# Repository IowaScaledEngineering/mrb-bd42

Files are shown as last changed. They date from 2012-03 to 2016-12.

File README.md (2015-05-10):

This is the software library, example applications, and hardware design files for the Iowa Scaled Engineering MRB-BD42 v3 4 Channel DCC block detector

The product can be found at:
http://www.iascaled.com/store/MRB-BD42

Hardware use documentation (the manual) can be found in the /doc/ directory.

Like all public Iowa Scaled Engineering designs, the MRB-BD42 is both open hardware and open source software.  Please refer to the hardware and software license files in this repository for details.

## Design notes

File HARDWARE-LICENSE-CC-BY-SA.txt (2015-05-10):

The hardware design files for the Iowa Scaled Engineering CKT-IRSENSE are
open hardware, and licensed under the Creative Commons Attribution-Share
Alike license.

A copy can be found below, or from 
  http://creativecommons.org/licenses/by-sa/4.0/legalcode
-----------------------------------------------------------------------------

Creative Commons Attribution-ShareAlike 4.0 International Public License

By exercising the Licensed Rights (defined below), You accept and agree to
be bound by the terms and conditions of this Creative Commons
Attribution-ShareAlike 4.0 International Public License ("Public License").
To the extent this Public License may be interpreted as a contract, You are
granted the Licensed Rights in consideration of Your acceptance of these
terms and conditions, and the Licensor grants You such rights in
consideration of benefits the Licensor receives from making the Licensed
Material available under these terms and conditions.

Section 1 – Definitions.

    Adapted Material means material subject to Copyright and Similar Rights
that is derived from or based upon the Licensed Material and in which the
Licensed Material is translated, altered, arranged, transformed, or
otherwise modified in a manner requiring permission under the Copyright and
Similar Rights held by the Licensor. For purposes of this Public License,
where the Licensed Material is a musical work, performance, or sound
recording, Adapted Material is always produced where the Licensed Material
is synched in timed relation with a moving image.
    Adapter's License means the license You apply to Your Copyright and
Similar Rights in Your contributions to Adapted Material in accordance with
the terms and conditions of this Public License.
    BY-SA Compatible License means a license listed at
creativecommons.org/compatiblelicenses, approved by Creative Commons as
essentially the equivalent of this Public License.
    Copyright and Similar Rights means copyright and/or similar rights
closely related to copyright including, without limitation, performance,
broadcast, sound recording, and Sui Generis Database Rights, without regard
to how the rights are labeled or categorized. For purposes of this Public
License, the rights specified in Section 2(b)(1)-(2) are not Copyright and
Similar Rights.
    Effective Technological Measures means those measures that, in the
absence of proper authority, may not be circumvented under laws fulfilling
obligations under Article 11 of the WIPO Copyright Treaty adopted on
December 20, 1996, and/or similar international agreements.
    Exceptions and Limitations means fair use, fair dealing, and/or any
other exception or limitation to Copyright and Similar Rights that applies
to Your use of the Licensed Material.
    License Elements means the license attributes listed in the name of a
Creative Commons Public License. The License Elements of this Public License
are Attribution and ShareAlike.
    Licensed Material means the artistic or literary work, database, or
other material to which the Licensor applied this Public License.
    Licensed Rights means the rights granted to You subject to the terms and
conditions of this Public License, which are limited to all Copyright and
Similar Rights that apply to Your use of the Licensed Material and that the
Licensor has authority to license.
    Licensor means the individual(s) or entity(ies) granting rights under
this Public License.
    Share means to provide material to the public by any means or process
that requires permission under the Licensed Rights, such as reproduction,
public display, public performance, distribution, dissemination,
communication, or importation, and to make material available to the public
including in ways that members of the public may access the material from a
place and at a time individually chosen by them.
    Sui Generis Database Rights means rights other than copyright resulting
from Directive 96/9/EC of the European Parliament and of the Council of 11
March 1996 on the legal protection of databases, as amended and/or
succeeded, as well as other essentially equivalent rights anywhere in the
world.
    You means the individual or entity exercising the Licensed Rights under
this Public License. Your has a corresponding meaning.

Section 2 – Scope.

    License grant.
        Subject to the terms and conditions of this Public License, the
Licensor hereby grants You a worldwide, royalty-free, non-sublicensable,
non-exclusive, irrevocable license to exercise the Licensed Rights in the
Licensed Material to:
            reproduce and Share the Licensed Material, in whole or in part;
and
            produce, reproduce, and Share Adapted Material.
        Exceptions and Limitations. For the avoidance of doubt, where
Exceptions and Limitations apply to Your use, this Public License does not
apply, and You do not need to comply with its terms and conditions.
        Term. The term of this Public License is specified in Section 6(a).
        Media and formats; technical modifications allowed. The Licensor
authorizes You to exercise the Licensed Rights in all media and formats
whether now known or hereafter created, and to make technical modifications
necessary to do so. The Licensor waives and/or agrees not to assert any
right or authority to forbid You from making technical modifications
necessary to exercise the Licensed Rights, including technical modifications
necessary to circumvent Effective Technological Measures. For purposes of
this Public License, simply making modifications authorized by this Section
2(a)(4) never produces Adapted Material.
        Downstream recipients.
            Offer from the Licensor – Licensed Material. Every recipient of
the Licensed Material automatically receives an offer from the Licensor to
exercise the Licensed Rights under the terms and conditions of this Public
License.
            Additional offer from the Licensor – Adapted Material. Every
recipient of Adapted Material from You automatically receives an offer from
the Licensor to exercise the Licensed Rights in the Adapted Material under
the conditions of the Adapter’s License You apply.
            No downstream restrictions. You may not offer or impose any
additional or different terms or conditions on, or apply any Effective
Technological Measures to, the Licensed Material if doing so restricts
exercise of the Licensed Rights by any recipient of the Licensed Material.
        No endorsement. Nothing in this Public License constitutes or may be
construed as permission to assert or imply that You are, or that Your use of
the Licensed Material is, connected with, or sponsored, endorsed, or granted
official status by, the Licensor or others designated to receive attribution
as provided in Section 3(a)(1)(A)(i).

    Other rights.
        Moral rights, such as the right of integrity, are not licensed under
this Public License, nor are publicity, privacy, and/or other similar
personality rights; however, to the extent possible, the Licensor waives
and/or agrees not to assert any such rights held by the Licensor to the
limited extent necessary to allow You to exercise the Licensed Rights, but
not otherwise.
        Patent and trademark rights are not licensed under this Public
License.
        To the extent possible, the Licensor waives any right to collect
royalties from You for the exercise of the Licensed Rights, whether directly
or through a collecting society under any voluntary or waivable statutory or
compulsory licensing scheme. In all other cases the Licensor expressly
reserves any right to collect such royalties.

Section 3 – License Conditions.

Your exercise of the Licensed Rights is expressly made subject to the
following conditions.

    Attribution.

        If You Share the Licensed Material (including in modified form), You
must:
            retain the following if it is supplied by the Licensor with the
Licensed Material:
                identification of the creator(s) of the Licensed Material
and any others designated to receive attribution, in any reasonable manner
requested by the Licensor (including by pseudonym if designated);
                a copyright notice;
                a notice that refers to this Public License;
                a notice that refers to the disclaimer of warranties;
                a URI or hyperlink to the Licensed Material to the extent
                reasonably practicable;
            indicate if You modified the Licensed Material and retain an
indication of any previous modifications; and
            indicate the Licensed Material is licensed under this Public
License, and include the text of, or the URI or hyperlink to, this Public
License.
        You may satisfy the conditions in Section 3(a)(1) in any reasonable
manner based on the medium, means, and context in which You Share the
Licensed Material. For example, it may be reasonable to satisfy the
conditions by providing a URI or hyperlink to a resource that includes the
required information.
        If requested by the Licensor, You must remove any of the information
required by Section 3(a)(1)(A) to the extent reasonably practicable.
    ShareAlike.

    In addition to the conditions in Section 3(a), if You Share Adapted
Material You produce, the following conditions also apply.
        The Adapter’s License You apply must be a Creative Commons license
with the same License Elements, this version or later, or a BY-SA Compatible
License.
        You must include the text of, or the URI or hyperlink to, the
Adapter's License You apply. You may satisfy this condition in any
reasonable manner based on the medium, means, and context in which You Share
Adapted Material.
        You may not offer or impose any additional or different terms or
conditions on, or apply any Effective Technological Measures to, Adapted
Material that restrict exercise of the rights granted under the Adapter's
License You apply.

Section 4 – Sui Generis Database Rights.

Where the Licensed Rights include Sui Generis Database Rights that apply to
Your use of the Licensed Material:

    for the avoidance of doubt, Section 2(a)(1) grants You the right to
extract, reuse, reproduce, and Share all or a substantial portion of the
contents of the database;
    if You include all or a substantial portion of the database contents in
a database in which You have Sui Generis Database Rights, then the database
in which You have Sui Generis Database Rights (but not its individual
contents) is Adapted Material, including for purposes of Section 3(b); and
    You must comply with the conditions in Section 3(a) if You Share all or
a substantial portion of the contents of the database.

For the avoidance of doubt, this Section 4 supplements and does not replace
Your obligations under this Public License where the Licensed Rights include
other Copyright and Similar Rights.

Section 5 – Disclaimer of Warranties and Limitation of Liability.

    Unless otherwise separately undertaken by the Licensor, to the extent
possible, the Licensor offers the Licensed Material as-is and as-available,
and makes no representations or warranties of any kind concerning the
Licensed Material, whether express, implied, statutory, or other. This
includes, without limitation, warranties of title, merchantability, fitness
for a particular purpose, non-infringement, absence of latent or other
defects, accuracy, or the presence or absence of errors, whether or not
known or discoverable. Where disclaimers of warranties are not allowed in
full or in part, this disclaimer may not apply to You.
    To the extent possible, in no event will the Licensor be liable to You
on any legal theory (including, without limitation, negligence) or otherwise
for any direct, special, indirect, incidental, consequential, punitive,
exemplary, or other losses, costs, expenses, or damages arising out of this
Public License or use of the Licensed Material, even if the Licensor has
been advised of the possibility of such losses, costs, expenses, or damages.
Where a limitation of liability is not allowed in full or in part, this
limitation may not apply to You.

    The disclaimer of warranties and limitation of liability provided above
shall be interpreted in a manner that, to the extent possible, most closely
approximates an absolute disclaimer and waiver of all liability.

Section 6 – Term and Termination.

    This Public License applies for the term of the Copyright and Similar
Rights licensed here. However, if You fail to comply with this Public
License, then Your rights under this Public License terminate automatically.

    Where Your right to use the Licensed Material has terminated under
Section 6(a), it reinstates:
        automatically as of the date the violation is cured, provided it is
cured within 30 days of Your discovery of the violation; or
        upon express reinstatement by the Licensor.
    For the avoidance of doubt, this Section 6(b) does not affect any right
the Licensor may have to seek remedies for Your violations of this Public
License.
    For the avoidance of doubt, the Licensor may also offer the Licensed
Material under separate terms or conditions or stop distributing the
Licensed Material at any time; however, doing so will not terminate this
Public License.
    Sections 1, 5, 6, 7, and 8 survive termination of this Public License.

Section 7 – Other Terms and Conditions.

    The Licensor shall not be bound by any additional or different terms or
conditions communicated by You unless expressly agreed.
    Any arrangements, understandings, or agreements regarding the Licensed
Material not stated herein are separate from and independent of the terms
and conditions of this Public License.

Section 8 – Interpretation.

    For the avoidance of doubt, this Public License does not, and shall not
be interpreted to, reduce, limit, restrict, or impose conditions on any use
of the Licensed Material that could lawfully be made without permission
under this Public License.
    To the extent possible, if any provision of this Public License is
deemed unenforceable, it shall be automatically reformed to the minimum
extent necessary to make it enforceable. If the provision cannot be
reformed, it shall be severed from this Public License without affecting the
enforceability of the remaining terms and conditions.
    No term or condition of this Public License will be waived and no
failure to comply consented to unless expressly agreed to by the Licensor.
    Nothing in this Public License constitutes or may be interpreted as a
limitation upon, or waiver of, any privileges and immunities that apply to
the Licensor or You, including from the legal processes of any jurisdiction
or authority.

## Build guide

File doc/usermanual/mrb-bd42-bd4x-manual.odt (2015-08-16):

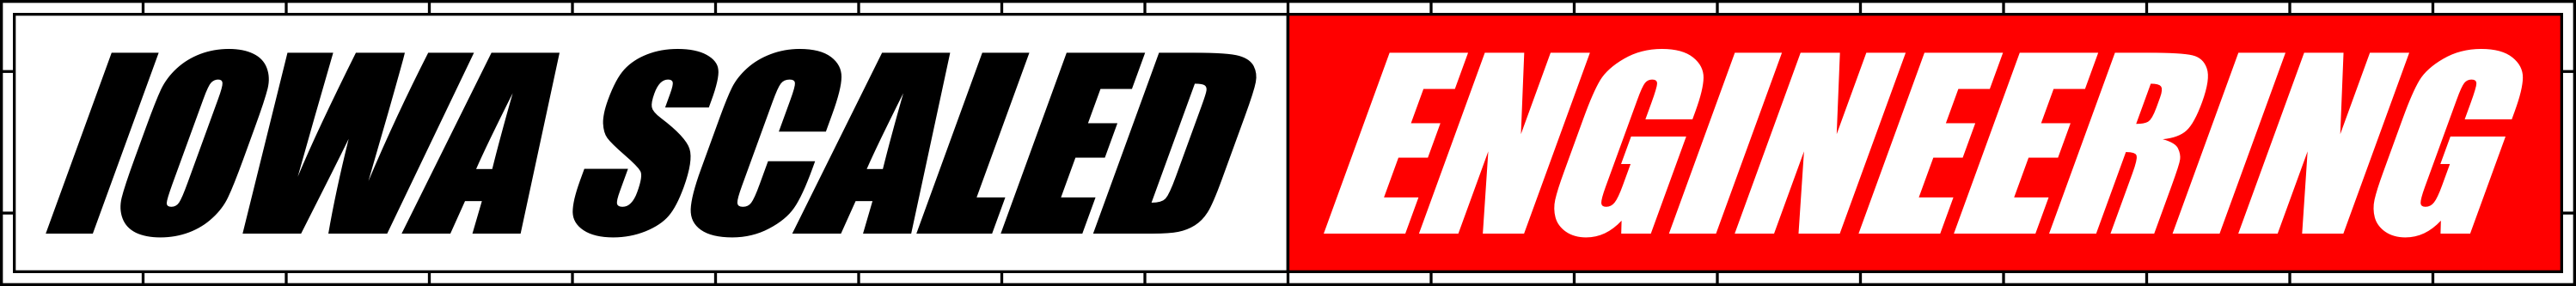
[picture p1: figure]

MRB-BD42 / MRB-BD4X v3 User Manual

# Features

- Four extremely sensitive (12-15k ohms) independent channels
- Easy per-channel sensitivity adjustment
- Isolated detection to prevent coupling track power and signal systems
- Simple installation doesn't require cutting track power wires
- Open source MRBus interface (MRB-BD42 version only)
- Expansion ports for up to two extra MRB-BD4X on every MRB-BD42 for up to 8 extra channels
- Four easy-to-use logic level outputs (5V @ 15mA maximum, MRB-BD4X version only)

# Applications

- Block detection for signaling systems
- Activate grade crossing signals
- Monitor train progress in hidden areas
- Simulating a spring switch using an MRServo switch machine

# Differences between MRB-BD42 vs MRB-BD4X

MRB-BD42 detectors are designed to integrate with MRBus, an open source model railroad control bus based on RS-485 and promoted by Iowa Scaled Engineering. For more information, see http://www.mrbus.org

MRB-BD4X detectors are designed to provide four 5V logic level outputs, each corresponding to one channel of the detector. These can be used independently, connected to your own signal logic, or as expansion modules for a MRB-BD42.

# Operation

The MRB-BD42/BD4X are four-channel current-based model railroad block occupancy detectors for DCC layouts. They require the alternating DCC signal to operate reliably, and will either not work or work erratically with most DC layouts.

The BD42/BD4X use current transformers – the large black tombstone-shaped items on the board – to sense small amounts of current used by DCC decoders and cars with resistor-equipped wheelsets. As such, they are electrically isolated from track power, preventing damaging currents from find stray paths between your boosters and your expensive signal gear.

# Using the MRB-BD4X Outputs

The MRB-BD4X has four logic-level outputs. Outputs will be high (5V) upon detection and low (0V) when not detecting. Never expose these outputs to a voltage outside that range, or draw more than 20 milliamps from them. To switch higher currents or voltages, please use something like our ACC-RELAY1 module.

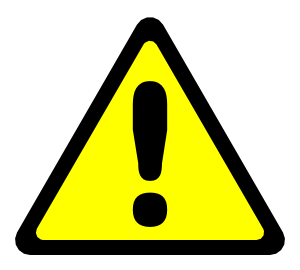
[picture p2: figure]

Do not exceed 20mA on any output, or short any output pin to 5V, GND, or any other voltage. Damage to the block detector will likely result.

# Using the MRB-BD42 Auxilliary Inputs

The MRB-BD42 comes with two 6p6c connectors that provide regulated +5VDC, GND, and four 5V logic level inputs. These can be used to connect additional MRB-BD4X expanders to have up to 12 block detection channels, or can be used for auxiliary digital inputs. Never exceed 5VDC on any of the input pins and do not draw more than 150mA from the 5V line if using them as auxiliary digital inputs from your own modules.

# Installation

Securely mount the MRB-BD42/BD4X to the model railroad benchwork using the four mounting holes provided. When choosing a mounting location, make sure nothing conductive will contact the back of the circuit board, as this may cause short circuits, malfunctions, and permanent damage.

### Powering the Detector

Both versions of the detector need a power supply to operate.

The MRB-BD42 requires 8-16VDC applied to the VIN and GND terminals. Typically this will be the MRBus power pair. The MRBus data pair should be connected to the A/B terminals, same as any MRBus node.

The MRB-BD4X can be fed from either 8-16VDC applied to the VIN and GND terminals, same as the BD42, or can be fed clean, regulated 5VDC through the 5V/GND terminals near the logic level ouputs.

Do not exceed 5V if feeding power through the 5V power supply input terminal. Power fed in through this terminal is neither regulated nor filtered, and exceeding 5V will cause the immediate destruction of the module.

### Wiring Blocks For Detection

For each block to be detected, gap at least one rail at each end of the block. Connect all the feeder wires for the gapped rail to a common bus wire, and run that wire through the center of the current transformer on the BD42/BD4X.

Only a single pass through the transformer is recommended, but for sensing very small currents, the wire can be looped through twice.

Note 1: DCC circuit breakers and auto-reversers draw a minute (but variable) amount of current, and will trigger the block detectors. Any breakers or reversing modules should be installed between the DCC booster and the BD42/BD4X, not between the detector and the track.

Note 2: For neatness and to minimize cross-talk between blocks, it's recommended to zip tie the two halves of the wire above the current transformer.

### Setting the Sensitivity

Contrary to popular belief, an empty track block does not always draw zero current. Because of resistive leakage through scenery (including wooden ties in varying humidity) and capacitive effects between the rails and feeder wires, there's often a very small leakage current.

The MRB-BD42/BD4X has an adjustment potentiometer (pot) on each channel to allow you to tune out this leakage current. Rotating the potentiometer clockwise will increase the sensitivity (detects occupancy at lower currents) and counter-clockwise will decrease sensitivity.

To tune each channel:

1) Turn on your DCC system and make sure no equipment is in the block.

2) If the red “detect” LED is on for the channel you're working on, you can skip this step. Otherwise, use a small flathead screwdriver to slowly turn the potentiometer clockwise until the red light just comes on.

3) Now turn the pot counter-clockwise slowly until the LED turns off. At this point, your channel is calibrated.

4) While not typical, it is possible that changes to the layout – humidity, temperature, ballasting the track, etc. - can change the leakage current. You may need to repeat the procedure if you get false occupancy in the future.

# Configuration Values

As a MRBus-based device, the MRB-BD42 has a number of configuration registers that can be used to change how the device operates.

The MRB-BD4X also uses many of these registers, but has no network through which to update them conveniently. For most applications, the default values will work without any issues. However, for more specialized applications, they can be changed from their default value using an AVR programmer.

CV | Purpose | Default | Possible Values | Description
0x00 | Node Address | 3 | 1-254 | The node address for this MRB-BD42
0x02 0x03 | Update Time H Update Time L | 20 | 1-65535 | Interval, in 1/10ths of seconds, at which occupancy updates are sent if there is no change
0x10 0x11 0x12 0x13 | Ch1 On Delay Ch2 On Delay Ch3 On Delay Ch4 On Delay | 4 | 1-254 | Delay between when occupancy is first detected on a channel and when the module indicates occupancy. The units are roughly 1/250th of a second. Larger numbers result in longer delays.
0x20 0x21 0x22 0x23 | Ch1 Off Delay Ch2 Off Delay Ch3 Off Delay Ch4 Off Delay | 25 | 1-254 | Delay between when occupancy is no longer detected on a channel and when the module returns to not indicating occupancy. The units are roughly 1/250th of a second. Larger numbers result in longer delays.
0x30 0x31 0x32 0x33 0x34 0x35 0x36 0x37 | Ch1 Threshold H Ch1 Threshold L Ch2 Threshold H Ch2 Threshold L Ch3 Threshold H Ch3 Threshold L Ch4 Threshold H Ch4 Threshold L | 65535 | 1-1023 | Sets the threshold current for when a block is considered “detected”. If value is 65535 (default), the input from the potentiometer will be used instead for setting the detection threshold.

# Open Design

Iowa Scaled Engineering is committed to creating open designs that users are free to build, modify, adapt, improve, and share with others.

### Hardware

The design of the CKT-IRSENSE hardware is open source hardware, and is made available under the terms of the Creative Commons Attribution-Share Alike v3.0 license, a copy of which is available from: http://creativecommons.org/licenses/by-sa/3.0/

Design files can be found on the Iowa Scaled Engineering website:

http://www.iascaled.com/store/ (http://www.iascaled.com/store/MRB-BD42)MRB-BD42 (http://www.iascaled.com/store/MRB-BD42)

http://www.iascaled.com/store/ (http://www.iascaled.com/store/MRB-BD42)MRB-BD4 (http://www.iascaled.com/store/MRB-BD42)X

### Firmware

The official Iowa Scaled Engineering firmware for the MRB-BD42 and MRB-BD4X is free software: you can redistribute it and/or modify it under the terms of the GNU General Public License as published by the Free Software Foundation, either version 3 of the License, or (at your option) any later version. A copy of the GNU GPL can be found at: http://www.gnu.org/licenses/gpl.html

New firmware can be flashed into the MRB-BD42/MRB-BD4X through J1. The six pin connectors is a standard AVR 6-pin ISP header.

Iowa Scaled Engineering

http://www.iascaled.com/ support@iascaled.com

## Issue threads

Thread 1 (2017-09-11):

Regulator to C1 spacing is tight

petersenm, 2017-09-11:

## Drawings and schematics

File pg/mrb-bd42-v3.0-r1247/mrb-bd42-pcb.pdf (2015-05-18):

# mrb-bd42.pcb

# 1. Table of Contents (This Page) Created on Mon Apr 20 14:27:32 2015

# 2. component 3. solder 4. outline 5. plated-drill 6. componentmask 7. soldermask 8. topsilk 9. bottomsilk 10. toppaste 11. topassembly 12. bottomassembly 13. fab

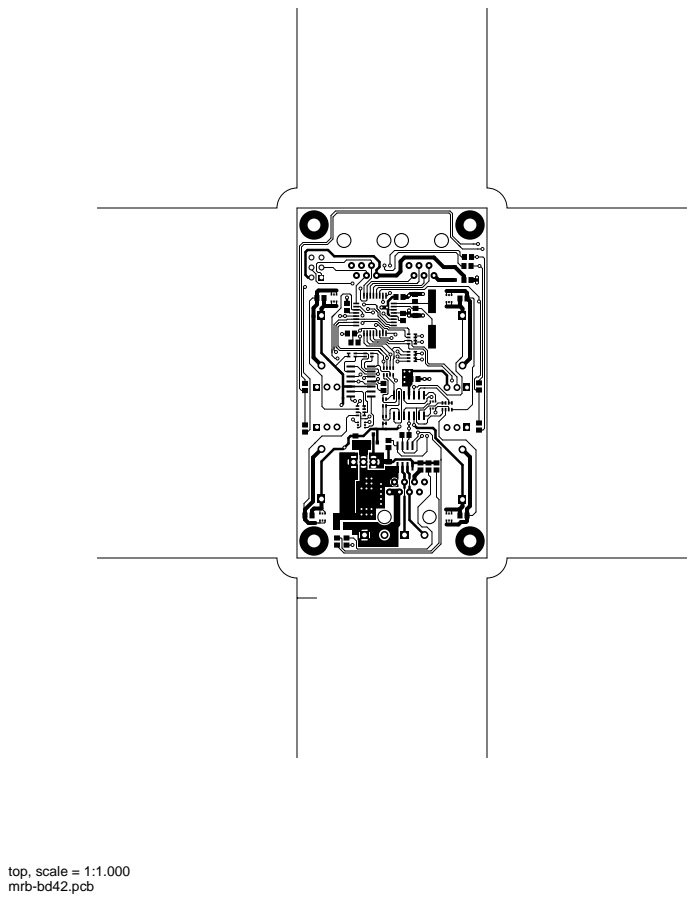
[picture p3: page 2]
top, scale = 1:1.000

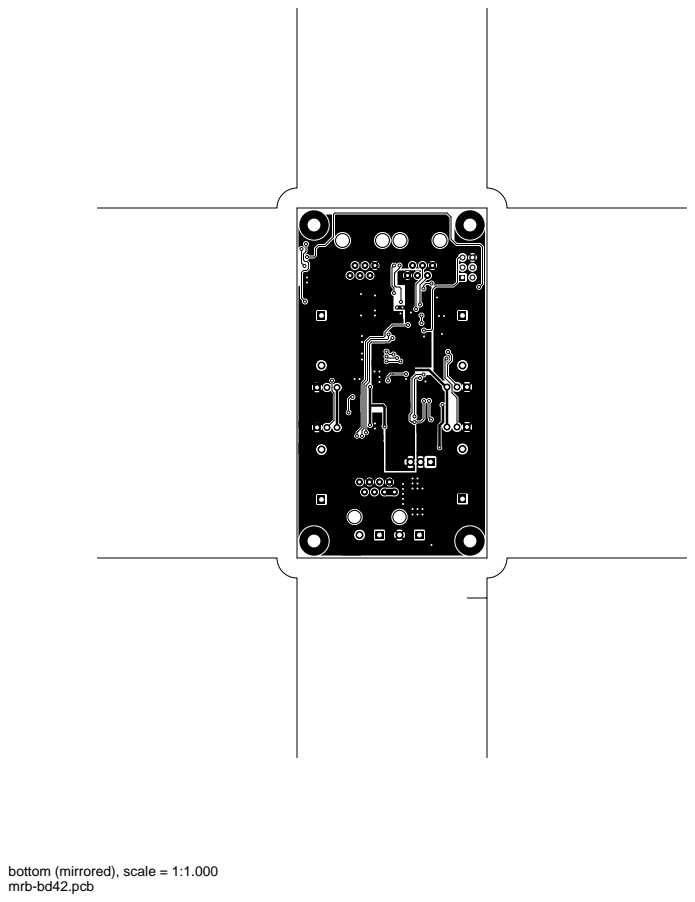
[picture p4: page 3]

bottom (mirrored), scale = 1:1.000

outline, scale = 1:1.000

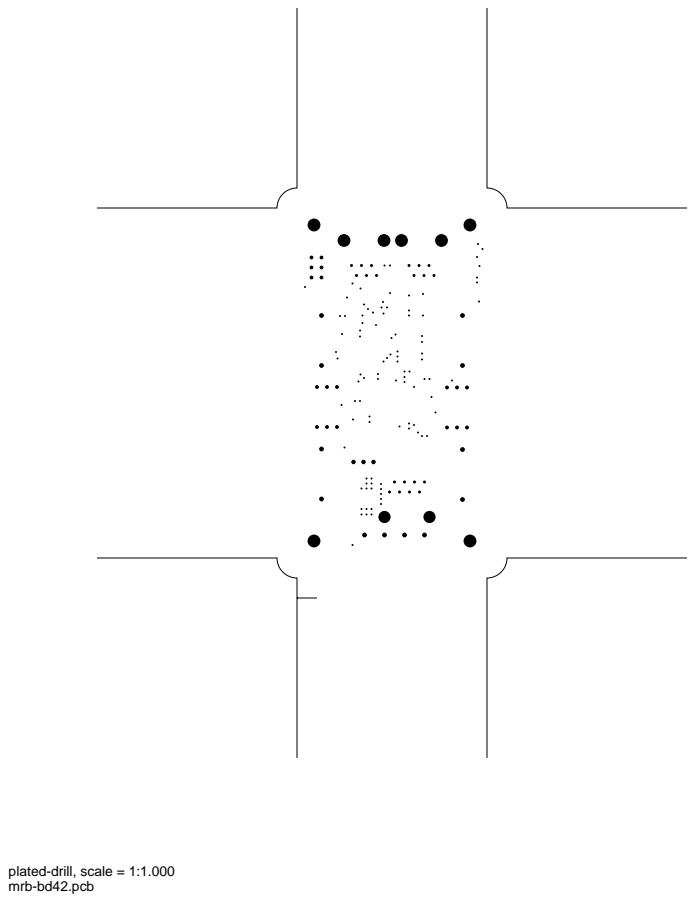
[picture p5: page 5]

plated-drill, scale = 1:1.000

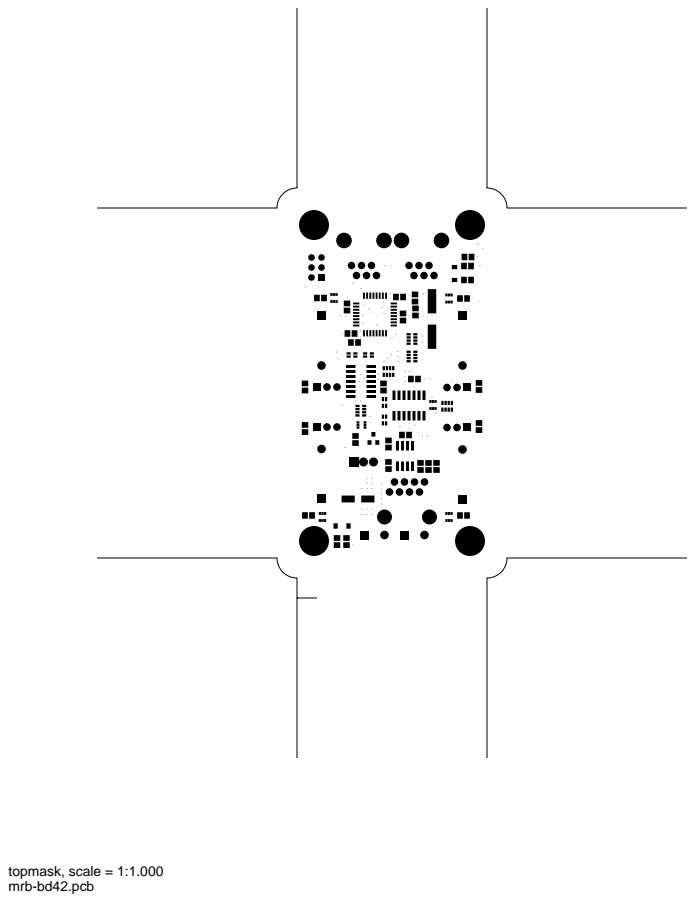
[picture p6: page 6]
topmask, scale = 1:1.000

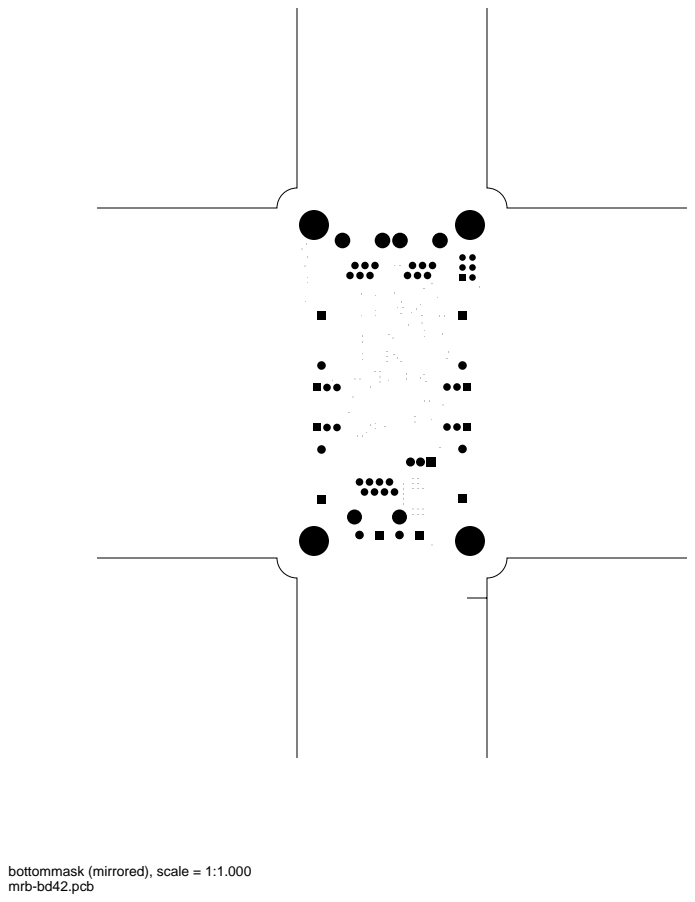
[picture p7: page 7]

bottommask (mirrored), scale = 1:1.000

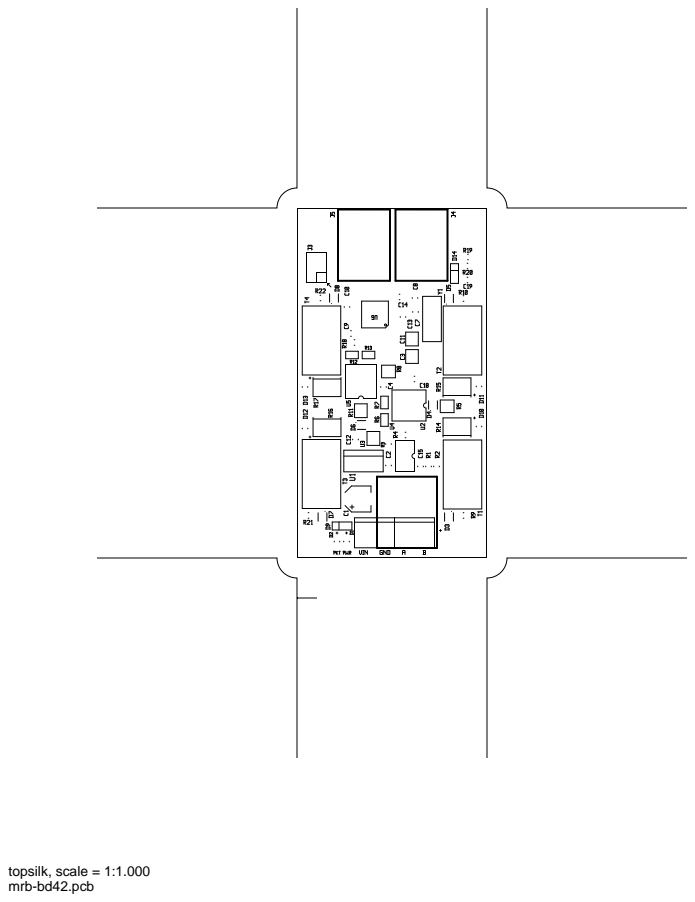
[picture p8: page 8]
topsilk, scale = 1:1.000

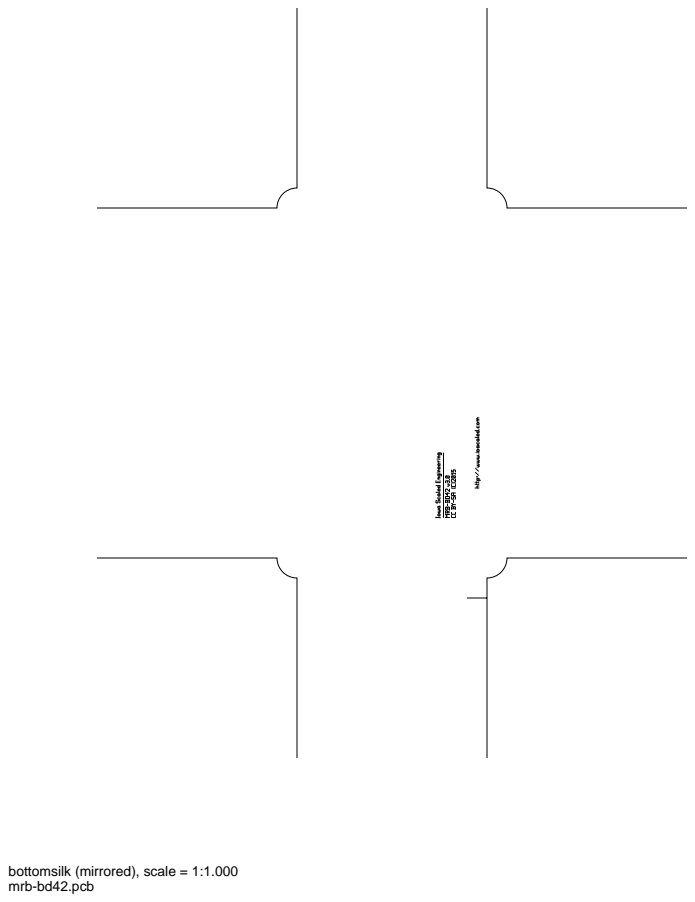
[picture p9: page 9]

bottomsilk (mirrored), scale = 1:1.000

toppaste, scale = 1:1.000

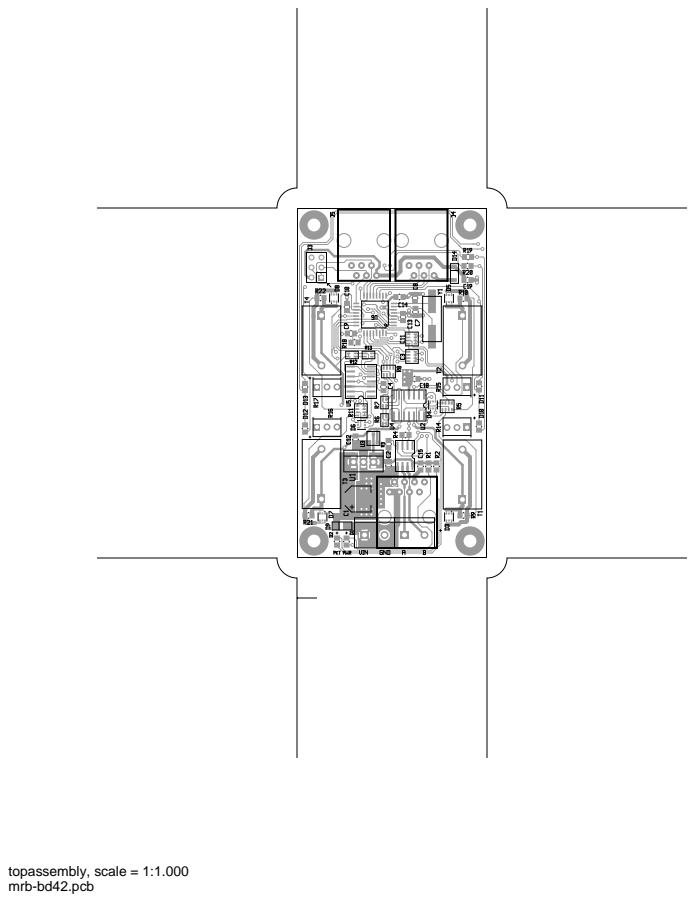
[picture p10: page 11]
topassembly, scale = 1:1.000

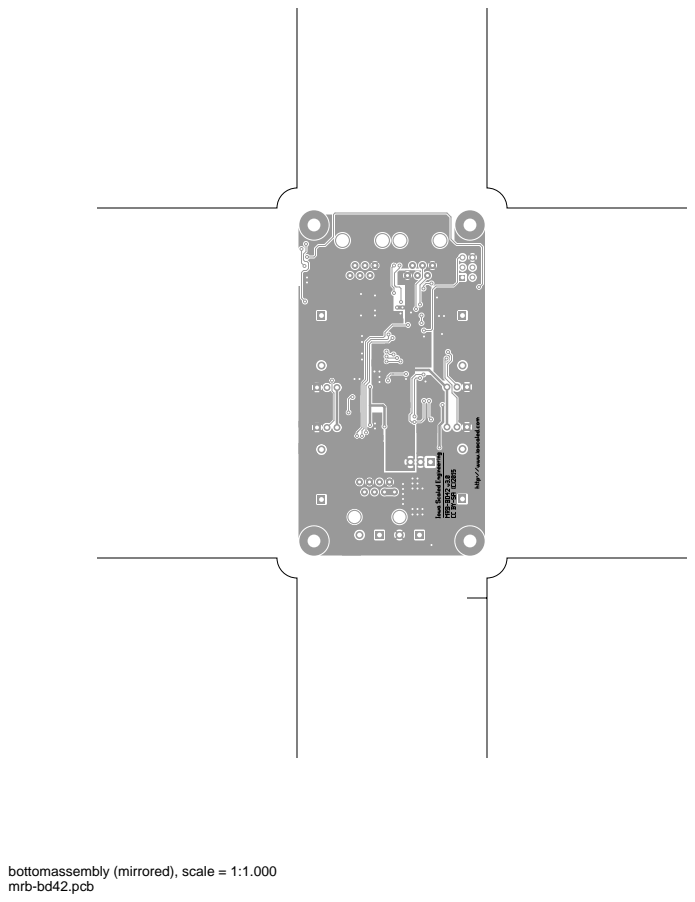
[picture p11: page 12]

bottomassembly (mirrored), scale = 1:1.000

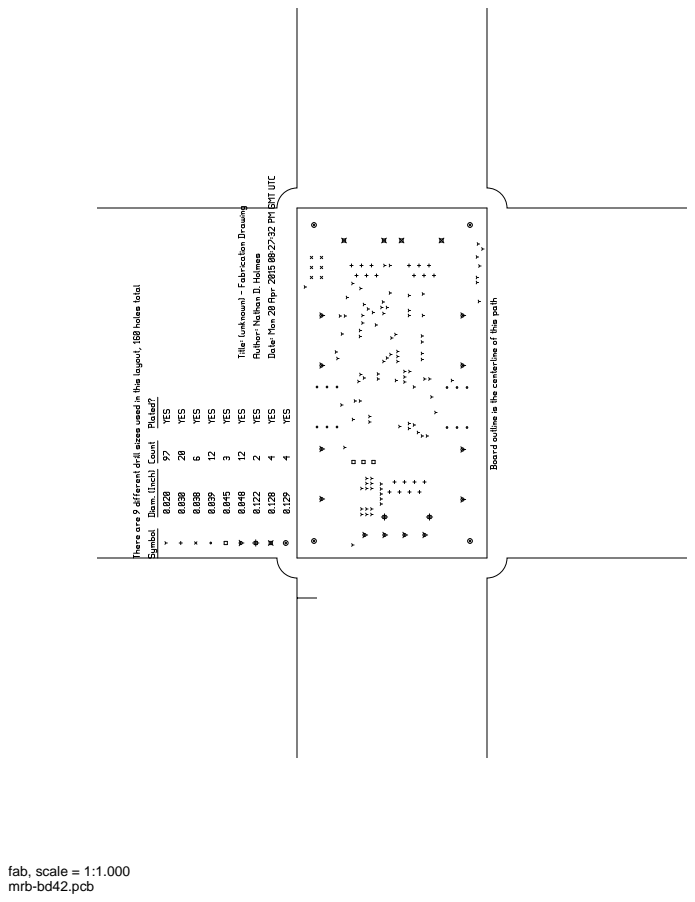
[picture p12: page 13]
fab, scale = 1:1.000

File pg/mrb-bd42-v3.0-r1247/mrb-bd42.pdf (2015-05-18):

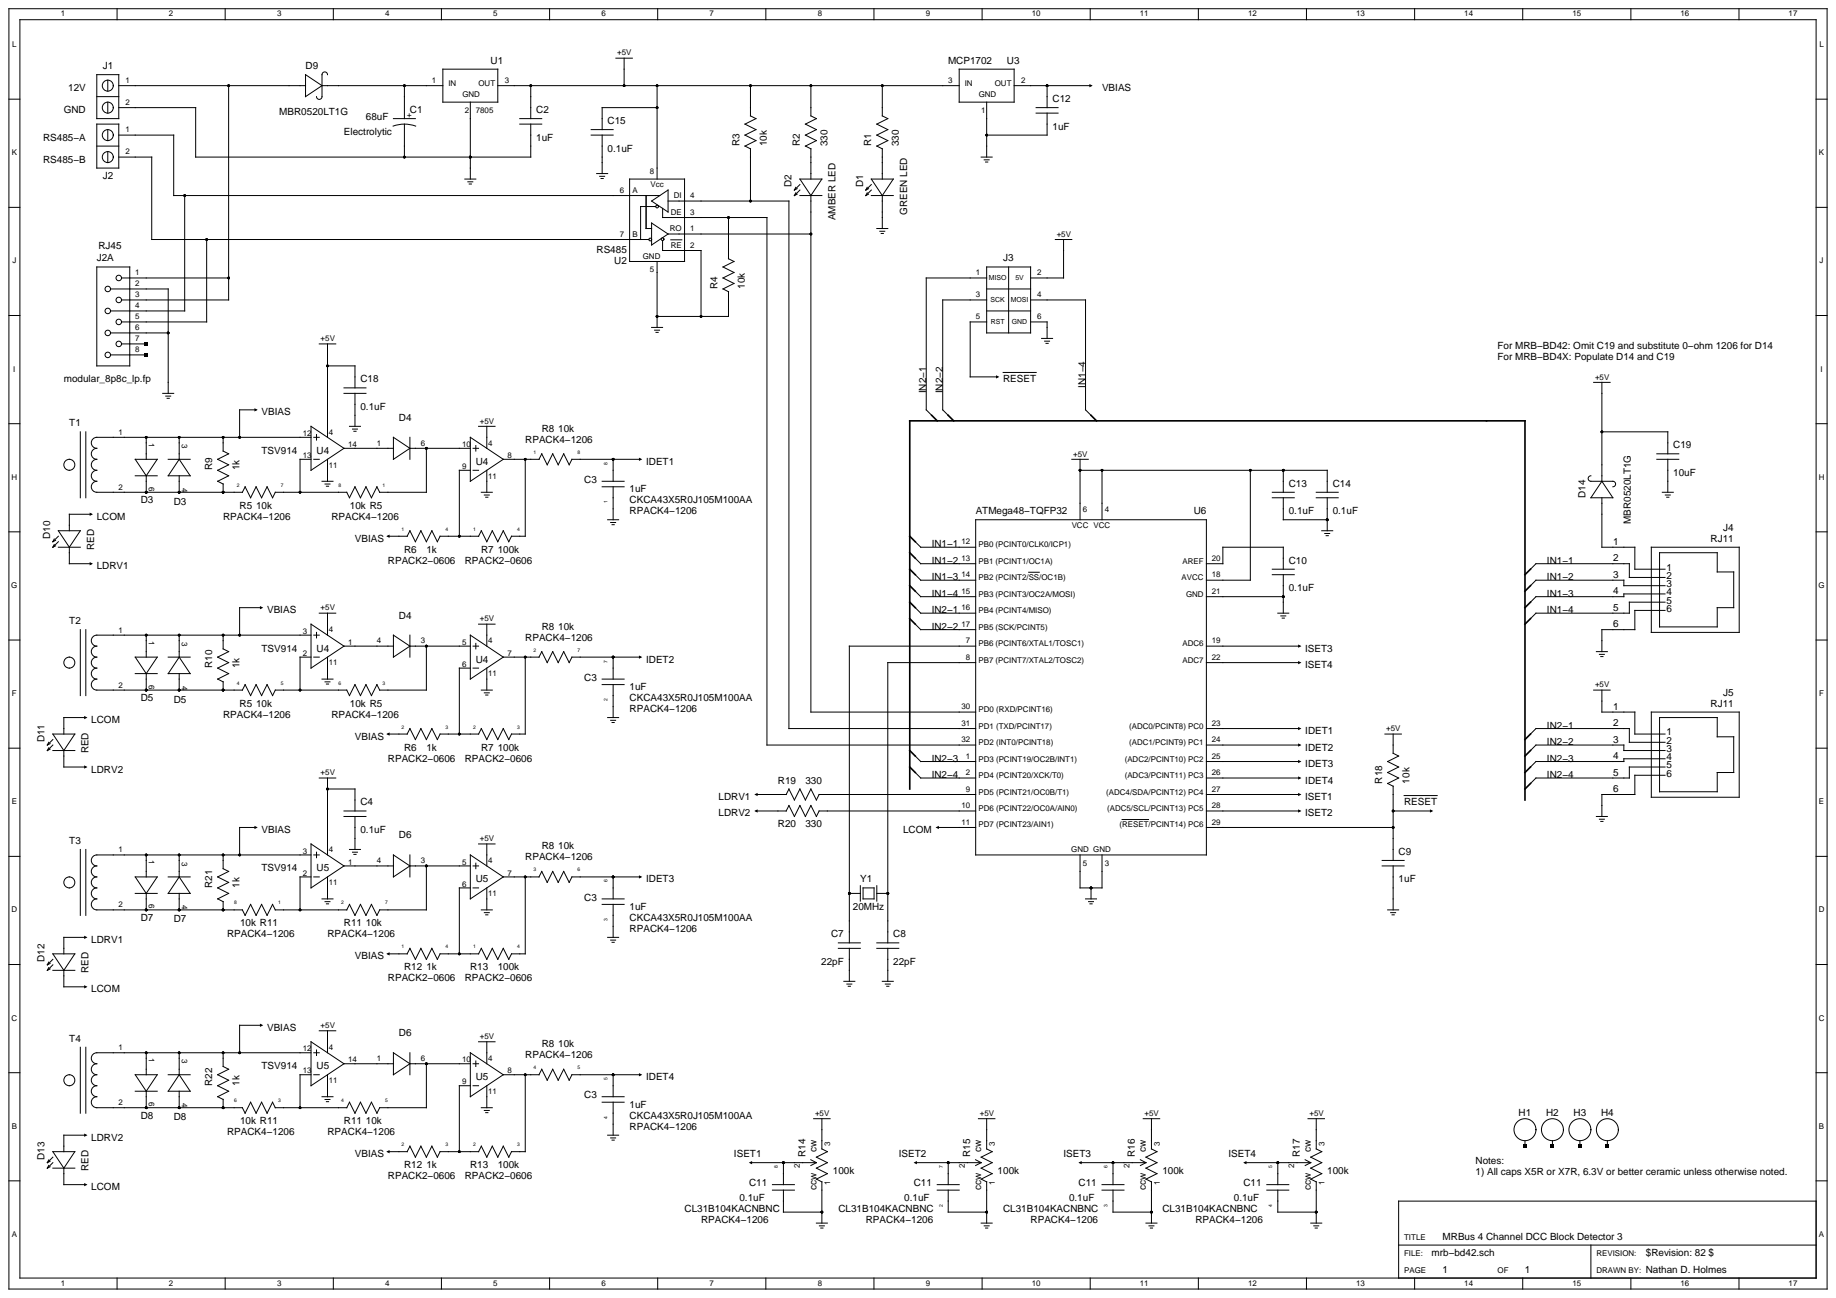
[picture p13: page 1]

For MRB−BD42: Omit C19 and substitute 0−ohm 1206 for D14
For MRB−BD4X: Populate D14 and C19

Notes:
1) All caps X5R or X7R, 6.3V or better ceramic unless otherwise noted.

MRBus 4 Channel DCC Block Detector 3
mrb−bd42.sch

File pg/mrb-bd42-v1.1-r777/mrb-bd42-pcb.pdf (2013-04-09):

# mrb-bd42.pcb

# 1. Table of Contents (This Page) Created on Mon Apr 8 21:49:42 2013

# 2. component 3. solder 4. plated-drill 5. componentmask 6. soldermask 7. topsilk 8. bottomsilk 9. toppaste 10. topassembly 11. bottomassembly 12. fab

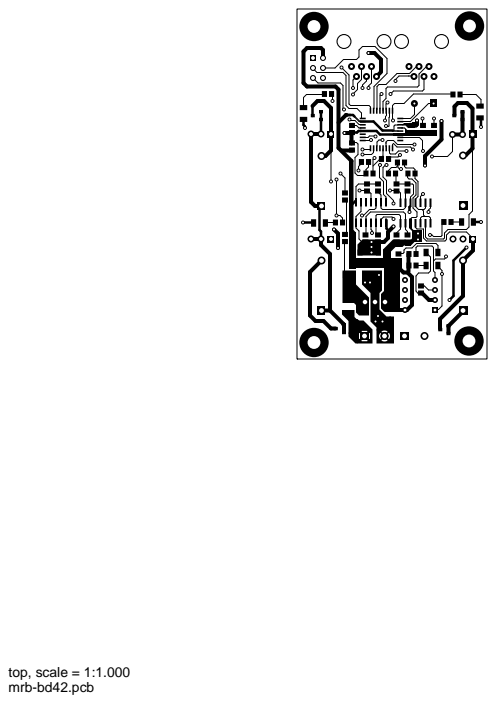
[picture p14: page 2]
top, scale = 1:1.000


bottom (mirrored), scale = 1:1.000


plated-drill, scale = 1:1.000

topmask, scale = 1:1.000


bottommask (mirrored), scale = 1:1.000

topsilk, scale = 1:1.000

bottomsilk (mirrored), scale = 1:1.000

toppaste, scale = 1:1.000

topassembly, scale = 1:1.000


bottomassembly (mirrored), scale = 1:1.000

fab, scale = 1:1.000

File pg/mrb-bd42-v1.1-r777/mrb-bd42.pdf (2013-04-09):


Place C11−C12 near AVR power pins
Place C13 near LM339 power pins
Place C14 near 74AC14 power pins

MISO | 5V

SCK | MOSI

ATMega48−TQFP32

Notes:
1) All caps ceramic unless otherwise noted.

MRBus 4 Channel DCC Block Detector II
mrb−bd42.sch

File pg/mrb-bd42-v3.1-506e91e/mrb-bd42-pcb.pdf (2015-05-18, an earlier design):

# mrb-bd42.pcb

# 1. Table of Contents (This Page) Created on Mon May 18 15:38:20 2015

# 2. component 3. solder 4. outline 5. plated-drill 6. componentmask 7. soldermask 8. topsilk 9. bottomsilk 10. toppaste 11. topassembly 12. bottomassembly 13. fab

top, scale = 1:1.000


bottom (mirrored), scale = 1:1.000

outline, scale = 1:1.000


plated-drill, scale = 1:1.000

topmask, scale = 1:1.000


bottommask (mirrored), scale = 1:1.000

topsilk, scale = 1:1.000

bottomsilk (mirrored), scale = 1:1.000

toppaste, scale = 1:1.000

topassembly, scale = 1:1.000


bottomassembly (mirrored), scale = 1:1.000

fab, scale = 1:1.000

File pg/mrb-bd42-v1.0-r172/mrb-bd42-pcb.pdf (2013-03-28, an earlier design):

# mrb-bd42.pcb

# 1. Table of Contents (This Page) Created on Thu Mar 28 16:57:23 2013

# 2. component 3. solder 4. plated-drill 5. componentmask 6. soldermask 7. topsilk 8. bottomsilk 9. toppaste 10. topassembly 11. bottomassembly 12. fab

top, scale = 1:1.000


bottom (mirrored), scale = 1:1.000


plated-drill, scale = 1:1.000

topmask, scale = 1:1.000


bottommask (mirrored), scale = 1:1.000

topsilk, scale = 1:1.000

bottomsilk (mirrored), scale = 1:1.000

toppaste, scale = 1:1.000

topassembly, scale = 1:1.000


bottomassembly (mirrored), scale = 1:1.000

fab, scale = 1:1.000

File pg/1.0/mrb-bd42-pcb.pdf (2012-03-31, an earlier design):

# mrb-bd42.pcb

# 1. Table of Contents (This Page) Created on Fri Mar 30 19:56:02 2012

# 2. component 3. solder 4. plated-drill 5. componentmask 6. soldermask 7. topsilk 8. bottomsilk 9. bottompaste 10. toppaste 11. topassembly 12. bottomassembly 13. fab

front, scale = 1:1.000


back (mirrored), scale = 1:1.000


plated-drill, scale = 1:1.000

frontmask, scale = 1:1.000


backmask (mirrored), scale = 1:1.000

frontsilk, scale = 1:1.000

backsilk (mirrored), scale = 1:1.000 backpaste (mirrored), scale = 1:1.000 frontpaste, scale = 1:1.000

frontassembly, scale = 1:1.000


backassembly (mirrored), scale = 1:1.000

fab, scale = 1:1.000

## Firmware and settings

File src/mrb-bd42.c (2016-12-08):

/*************************************************************************
Title:    MRBus MRB-BD42 v3 firmware
Authors:  Nathan D. Holmes <maverick@drgw.net>
File:     $Id: $
License:  GNU General Public License v3

LICENSE:
    Copyright (C) 2015 Nathan Holmes

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
*************************************************************************/

#include <stdlib.h>
#include <avr/io.h>
#include <avr/interrupt.h>
#include <avr/eeprom.h>
#include <avr/wdt.h>
#include <util/delay.h>

#include "mrbus.h"

#define MRBUS_TX_BUFFER_DEPTH 4
#define MRBUS_RX_BUFFER_DEPTH 4

MRBusPacket mrbusTxPktBufferArray[MRBUS_TX_BUFFER_DEPTH];
MRBusPacket mrbusRxPktBufferArray[MRBUS_RX_BUFFER_DEPTH];

uint8_t mrbus_dev_addr = 0;
volatile uint8_t eventFlags = 0;
#define EVENT_DO_BD_READ 0x01

uint8_t internalBDStatus = 0;
uint8_t externalBDStatus = 0;

uint8_t channelOnDelayCount[4] = {0, 0, 0, 0};
uint8_t channelOffDelayCount[4] = {0, 0, 0, 0};
uint8_t channelOnDelay[4] = {4, 4, 4, 4};
uint8_t channelOffDelay[4] = {25, 25, 25, 25};

uint16_t eepromThreshold[4];

#define MRBUS_EE_CHANNEL0_ON_DELAY  0x10
#define MRBUS_EE_CHANNEL1_ON_DELAY  0x11
#define MRBUS_EE_CHANNEL2_ON_DELAY  0x12
#define MRBUS_EE_CHANNEL3_ON_DELAY  0x13

#define MRBUS_EE_CHANNEL0_OFF_DELAY  0x20
#define MRBUS_EE_CHANNEL1_OFF_DELAY  0x21
#define MRBUS_EE_CHANNEL2_OFF_DELAY  0x22
#define MRBUS_EE_CHANNEL3_OFF_DELAY  0x23

#define MRBUS_EE_CHANNEL0_THRESHOLD_H 0x30
#define MRBUS_EE_CHANNEL0_THRESHOLD_L 0x31

volatile uint16_t adcValue[8];


// ******** Start 100 Hz Timer, 0.16% error version (Timer 0)
// If you can live with a slightly less accurate timer, this one only uses Timer 0, leaving Timer 1 open
// for more advanced things that actually need a 16 bit timer/counter

// Initialize a 100Hz timer for use in triggering events.
// If you need the timer resources back, you can remove this, but I find it
// rather handy in triggering things like periodic status transmissions.
// If you do remove it, be sure to yank the interrupt handler and ticks/secs as well
// and the call to this function in the main function

volatile uint8_t ticks = 0;
volatile uint16_t decisecs=0;
volatile uint16_t update_decisecs=10;
volatile uint8_t busTimeout = 0;

void initialize100HzTimer(void)
{
	// Set up timer 0 for 100Hz interrupts
	TCNT0 = 0;
	OCR0A = 0xC2;
	ticks = 0;
	decisecs = 0;
	TCCR0A = _BV(WGM01);
	TCCR0B = _BV(CS02) | _BV(CS00);
	TIMSK0 |= _BV(OCIE0A);
}


ISR(TIMER0_COMPA_vect)
{
	uint8_t newLedValue;
	
	if (++ticks >= 10)
	{
		ticks = 0;
		decisecs++;
	}

	if (busTimeout)
		busTimeout--;

	if (ticks & 0x01)
	{
		newLedValue = 0xE0;
	
		if (internalBDStatus & 0x01)
			newLedValue &= ~0x20;
		if (internalBDStatus & 0x02)
			newLedValue &= ~0x40;
	} else {
		newLedValue = 0x00;

		if (internalBDStatus & 0x04)
			newLedValue |= 0x20;
		if (internalBDStatus & 0x08)
			newLedValue |= 0x40;
	}

	PORTD = (PORTD & 0x1F) | newLedValue;
}

// End of 100Hz timer

void initializeADC()
{
	for(uint8_t i=0; i<8; i++)
		adcValue[i] = 0;

	// Setup ADC for bus voltage monitoring
	ADMUX  = 0x40;  // AVCC reference, ADC0 starting channel
	ADCSRA = _BV(ADIF) | _BV(ADPS2) | _BV(ADPS1) | _BV(ADPS0); // 128 prescaler
	ADCSRB = 0x00;
	DIDR0  = 0x3F;  // Turn all ADC pins 0-5 into analog inputs
	ADCSRA |= _BV(ADEN) | _BV(ADSC) | _BV(ADIE) | _BV(ADIF);
}

ISR(ADC_vect)
{
	static uint8_t workingChannel = 0;
	static uint16_t accumulator = 0;
	static uint8_t count = 0;
	
	accumulator += ADC;
	if (++count >= 64)
	{
		adcValue[workingChannel] = accumulator / 64;
		accumulator = 0;
		count = 0;
		workingChannel++;
		
		ADMUX = (ADMUX & 0xF0) | (workingChannel & 0x07);
		
		if (8 == workingChannel)
		{
			workingChannel = 0;
			eventFlags |= EVENT_DO_BD_READ;
		}
	}

	if (0 == (eventFlags & EVENT_DO_BD_READ))
	{
		// Trigger the next conversion.  Not using auto-trigger so that we can safely change channels
		ADCSRA |= _BV(ADSC);
	}
}

void PktHandler(void)
{
	uint16_t crc = 0;
	uint8_t i;
	uint8_t rxBuffer[MRBUS_BUFFER_SIZE];
	uint8_t txBuffer[MRBUS_BUFFER_SIZE];

	if (0 == mrbusPktQueuePop(&mrbusRxQueue, rxBuffer, sizeof(rxBuffer)))
		return;


	//*************** PACKET FILTER ***************
	// Loopback Test - did we send it?  If so, we probably want to ignore it
	if (rxBuffer[MRBUS_PKT_SRC] == mrbus_dev_addr) 
		goto	PktIgnore;

	// Destination Test - is this for us or broadcast?  If not, ignore
	if (0xFF != rxBuffer[MRBUS_PKT_DEST] && mrbus_dev_addr != rxBuffer[MRBUS_PKT_DEST]) 
		goto	PktIgnore;
	
	// CRC16 Test - is the packet intact?
	for(i=0; i<rxBuffer[MRBUS_PKT_LEN]; i++)
	{
		if ((i != MRBUS_PKT_CRC_H) && (i != MRBUS_PKT_CRC_L)) 
			crc = mrbusCRC16Update(crc, rxBuffer[i]);
	}
	if ((UINT16_HIGH_BYTE(crc) != rxBuffer[MRBUS_PKT_CRC_H]) || (UINT16_LOW_BYTE(crc) != rxBuffer[MRBUS_PKT_CRC_L]))
		goto	PktIgnore;
		
	//*************** END PACKET FILTER ***************


	//*************** PACKET HANDLER - PROCESS HERE ***************

	// Just smash the transmit buffer if we happen to see a packet directed to us
	// that requires an immediate response
	//
	// If we're in here, then either we're transmitting, then we can't be 
	// receiving from someone else, or we failed to transmit whatever we were sending
	// and we're waiting to try again.  Either way, we're not going to corrupt an
	// in-progress transmission.
	//
	// All other non-immediate transmissions (such as scheduled status updates)
	// should be sent out of the main loop so that they don't step on things in
	// the transmit buffer
	
	if ('A' == rxBuffer[MRBUS_PKT_TYPE])
	{
		// PING packet
		txBuffer[MRBUS_PKT_DEST] = rxBuffer[MRBUS_PKT_SRC];
		txBuffer[MRBUS_PKT_SRC] = mrbus_dev_addr;
		txBuffer[MRBUS_PKT_LEN] = 6;
		txBuffer[MRBUS_PKT_TYPE] = 'a';
		mrbusPktQueuePush(&mrbusTxQueue, txBuffer, txBuffer[MRBUS_PKT_LEN]);
		goto PktIgnore;
	} 
	else if ('W' == rxBuffer[MRBUS_PKT_TYPE]) 
	{
		// EEPROM WRITE Packet
		txBuffer[MRBUS_PKT_DEST] = rxBuffer[MRBUS_PKT_SRC];
		txBuffer[MRBUS_PKT_LEN] = 8;			
		txBuffer[MRBUS_PKT_TYPE] = 'w';
		eeprom_write_byte((uint8_t*)(uint16_t)rxBuffer[6], rxBuffer[7]);
		txBuffer[6] = rxBuffer[6];
		txBuffer[7] = rxBuffer[7];
		if (MRBUS_EE_DEVICE_ADDR == rxBuffer[6])
			mrbus_dev_addr = eeprom_read_byte((uint8_t*)MRBUS_EE_DEVICE_ADDR);
		txBuffer[MRBUS_PKT_SRC] = mrbus_dev_addr;
		mrbusPktQueuePush(&mrbusTxQueue, txBuffer, txBuffer[MRBUS_PKT_LEN]);
		goto PktIgnore;	
	}
	else if ('R' == rxBuffer[MRBUS_PKT_TYPE]) 
	{
		// EEPROM READ Packet
		txBuffer[MRBUS_PKT_DEST] = rxBuffer[MRBUS_PKT_SRC];
		txBuffer[MRBUS_PKT_SRC] = mrbus_dev_addr;
		txBuffer[MRBUS_PKT_LEN] = 8;			
		txBuffer[MRBUS_PKT_TYPE] = 'r';
		txBuffer[6] = rxBuffer[6];
		txBuffer[7] = eeprom_read_byte((uint8_t*)(uint16_t)rxBuffer[6]);			
		mrbusPktQueuePush(&mrbusTxQueue, txBuffer, txBuffer[MRBUS_PKT_LEN]);
		goto PktIgnore;
	}
	else if ('V' == rxBuffer[MRBUS_PKT_TYPE]) 
	{
		// Version
		txBuffer[MRBUS_PKT_DEST] = rxBuffer[MRBUS_PKT_SRC];
		txBuffer[MRBUS_PKT_SRC] = mrbus_dev_addr;
		txBuffer[MRBUS_PKT_LEN] = 16;
		txBuffer[MRBUS_PKT_TYPE] = 'v';
		txBuffer[6]  = MRBUS_VERSION_WIRED;
#ifndef GIT_REV
// This stubs in GIT_REV to 0 in case the make system isn't providing the current SVN revisions
#define GIT_REV=0L
#endif				
		txBuffer[7]  = 0xFF & ((uint32_t)(GIT_REV))>>16; // Software Revision
		txBuffer[8]  = 0xFF & ((uint32_t)(GIT_REV))>>8; // Software Revision
		txBuffer[9]  = 0xFF & (GIT_REV); // Software Revision
		txBuffer[10]  = 3; // Hardware Major Revision
		txBuffer[11]  = 1; // Hardware Minor Revision
		txBuffer[12] = 'B';
		txBuffer[13] = 'D';
		txBuffer[14] = '4';
		txBuffer[15] = '2';
		mrbusPktQueuePush(&mrbusTxQueue, txBuffer, txBuffer[MRBUS_PKT_LEN]);
		goto PktIgnore;
	}
	else if ('X' == rxBuffer[MRBUS_PKT_TYPE]) 
	{
		// Reset
		cli();
		wdt_reset();
		MCUSR &= ~(_BV(WDRF));
		WDTCSR |= _BV(WDE) | _BV(WDCE);
		WDTCSR = _BV(WDE);
		while(1);  // Force a watchdog reset
		sei();
	}

	//*************** END PACKET HANDLER  ***************

	
	//*************** RECEIVE CLEANUP ***************
PktIgnore:
	// Yes, I hate gotos as well, but sometimes they're a really handy and efficient
	// way to jump to a common block of cleanup code at the end of a function 

	// This section resets anything that needs to be reset in order to allow us to receive
	// another packet.  Typically, that's just clearing the MRBUS_RX_PKT_READY flag to 
	// indicate to the core library that the mrbus_rx_buffer is clear.
	
	
	return;	
}

#define PORTB_IN_BITS 0x3F
#define PORTC_IN_BITS 0xFF
#define PORTD_IN_BITS 0x18

void init(void)
{
	// Clear watchdog (in the case of an 'X' packet reset)
	MCUSR = 0;
#ifdef ENABLE_WATCHDOG
	// If you don't want the watchdog to do system reset, remove this chunk of code
	wdt_reset();
	WDTCSR |= _BV(WDE) | _BV(WDCE);
	WDTCSR = _BV(WDE) | _BV(WDP2) | _BV(WDP1); // Set the WDT to system reset and 1s timeout
	wdt_reset();
#else
	wdt_reset();
	wdt_disable();
#endif	

	// Turn the correct bits to inputs
	DDRB = ~(PORTB_IN_BITS);
	DDRC = 0xFF & ~(PORTC_IN_BITS);
	DDRD = ~(PORTD_IN_BITS);
	
	// Turn on pull-ups
	PORTB |= PORTB_IN_BITS;
	PORTC |= PORTC_IN_BITS;
	PORTD |= PORTD_IN_BITS;

	// Initialize MRBus address from EEPROM
	mrbus_dev_addr = eeprom_read_byte((uint8_t*)MRBUS_EE_DEVICE_ADDR);
	// Bogus addresses, fix to default address
	if (0xFF == mrbus_dev_addr || 0x00 == mrbus_dev_addr)
	{
		mrbus_dev_addr = 0x03;
		eeprom_write_byte((uint8_t*)MRBUS_EE_DEVICE_ADDR, mrbus_dev_addr);
	}
	
	update_decisecs = (uint16_t)eeprom_read_byte((uint8_t*)MRBUS_EE_DEVICE_UPDATE_L) 
		| (((uint16_t)eeprom_read_byte((uint8_t*)MRBUS_EE_DEVICE_UPDATE_H)) << 8);

	if (0xFFFF == update_decisecs)
	{
		// It's uninitialized - go ahead and set it to 2 seconds
		eeprom_write_byte((uint8_t*)MRBUS_EE_DEVICE_UPDATE_L, 20);
		eeprom_write_byte((uint8_t*)MRBUS_EE_DEVICE_UPDATE_H, 0);

		update_decisecs = (uint16_t)eeprom_read_byte((uint8_t*)MRBUS_EE_DEVICE_UPDATE_L) 
			| (((uint16_t)eeprom_read_byte((uint8_t*)MRBUS_EE_DEVICE_UPDATE_H)) << 8);
	}
	// This line assures that update_decisecs is at least 1
	update_decisecs = max(1, update_decisecs);

	for (uint8_t channel = 0; channel < 4; channel++)
	{
		channelOnDelay[channel] = eeprom_read_byte((uint8_t*)(MRBUS_EE_CHANNEL0_ON_DELAY + channel));
		if (0xFF == channelOnDelay[channel] || 0x00 == channelOnDelay[channel])
		{
			eeprom_write_byte((uint8_t*)(MRBUS_EE_CHANNEL0_ON_DELAY + channel), 4);
			channelOnDelay[channel] = eeprom_read_byte((uint8_t*)(MRBUS_EE_CHANNEL0_ON_DELAY + channel));			
		}

		channelOffDelay[channel] = eeprom_read_byte((uint8_t*)(MRBUS_EE_CHANNEL0_OFF_DELAY + channel));
		if (0xFF == channelOffDelay[channel] || 0x00 == channelOnDelay[channel])
		{
			eeprom_write_byte((uint8_t*)(MRBUS_EE_CHANNEL0_OFF_DELAY + channel), 25);
			channelOffDelay[channel] = eeprom_read_byte((uint8_t*)(MRBUS_EE_CHANNEL0_OFF_DELAY + channel));			
		}
		
		eepromThreshold[channel] = (uint16_t)eeprom_read_byte((uint8_t*)(MRBUS_EE_CHANNEL0_THRESHOLD_L + channel*2)) 
		| (((uint16_t)eeprom_read_byte((uint8_t*)(MRBUS_EE_CHANNEL0_THRESHOLD_H + channel * 2))) << 8);
		if (eepromThreshold[channel] > 1023)
		{
			eeprom_write_byte((uint8_t*)(MRBUS_EE_CHANNEL0_THRESHOLD_L + channel*2), 0xFF);
			eeprom_write_byte((uint8_t*)(MRBUS_EE_CHANNEL0_THRESHOLD_H + channel*2), 0xFF);
			eepromThreshold[channel] = (uint16_t)eeprom_read_byte((uint8_t*)(MRBUS_EE_CHANNEL0_THRESHOLD_L + channel*2)) 
			| (((uint16_t)eeprom_read_byte((uint8_t*)(MRBUS_EE_CHANNEL0_THRESHOLD_H + channel * 2))) << 8);
		}
		
	}
}


void readInternalDetectors(void)
{	
	for(uint8_t channel = 0; channel < 4; channel++)
	{
		uint16_t threshold = (0xFFFF == eepromThreshold[channel])?adcValue[channel+4]:eepromThreshold[channel];
		uint8_t channelMask = (1<<channel);

		// Introduce a bit of hysteresis. 
		// If the channel is currently "on", lower the threshold by 5 counts
		// If the channel is currently "off", raise the threshold by 5
		if ((internalBDStatus & channelMask) && (threshold >= 5))
		{
			threshold -= 5;
		} 
		else if ( (0 == (internalBDStatus & channelMask)) && (threshold <= (1023-5)) )
		{
			threshold += 5;
		}
	
		if (adcValue[channel] > threshold)
		{
			// Current for the channel has exceeded threshold
			
			if (0 == (internalBDStatus & channelMask))
			{
				// Channel is currently in a non-detecting state
				// Wait for the turnon delay before actually indicating on
				if (channelOnDelayCount[channel] < channelOnDelay[channel])
					channelOnDelayCount[channel]++;
				else
				{
					internalBDStatus |= channelMask;
					channelOffDelayCount[channel] = 0;
				}
			} else {
				// Channel is currently in a detecting state
				channelOffDelayCount[channel] = 0;
			}
		} else {
			// Current for the channel is under the threshold value
			if (internalBDStatus & channelMask)
			{
				// Channel is currently in a non-detecting state
				if (channelOffDelayCount[channel] < channelOffDelay[channel])
					channelOffDelayCount[channel]++;
				else
				{
					internalBDStatus &= ~(channelMask);
					channelOnDelayCount[channel] = 0;
				}
			} else {
				// Channel is currently in a detecting state
				channelOnDelayCount[channel] = 0;
			}
		}
	}
}

uint8_t debounce(uint8_t debouncedState, uint8_t newInputs)
{
	static uint8_t clock_A=0, clock_B=0;
	uint8_t delta = newInputs ^ debouncedState;   //Find all of the changes
	uint8_t changes;

	clock_A ^= clock_B;                     //Increment the counters
	clock_B  = ~clock_B;

	clock_A &= delta;                       //Reset the counters if no changes
	clock_B &= delta;                       //were detected.

	changes = ~((~delta) | clock_A | clock_B);
	debouncedState ^= changes;
	return(debouncedState);
}

void readExternalDetectors()
{
	uint8_t currentInputs = (PINB & 0x3F) | (0xC0 & (PIND<<3));
	externalBDStatus = debounce(externalBDStatus, currentInputs);
}

uint8_t readDetectors(void)
{
	static uint8_t old_internalBDStatus = 0;
	static uint8_t old_externalBDStatus = 0;
	uint8_t changed = 0;
	
	// Okay, we've got a new scan of all ADC inputs
	// Do some stuff
	readInternalDetectors();
	readExternalDetectors();

	if (old_internalBDStatus != internalBDStatus
		|| old_externalBDStatus != externalBDStatus)
	{
		old_internalBDStatus = internalBDStatus;
		old_externalBDStatus = externalBDStatus;
		changed = 1;
	}
	
	// Returns 0 if no change, 1 if change
	return changed;
}


int main(void)
{
	uint8_t changed = 0;

	// Application initialization
	init();
	initializeADC();

	// Initialize a 100 Hz timer.  See the definition for this function - you can
	// remove it if you don't use it.
	initialize100HzTimer();

	// Initialize MRBus core
	mrbusPktQueueInitialize(&mrbusTxQueue, mrbusTxPktBufferArray, MRBUS_TX_BUFFER_DEPTH);
	mrbusPktQueueInitialize(&mrbusRxQueue, mrbusRxPktBufferArray, MRBUS_RX_BUFFER_DEPTH);
	mrbusInit();

	sei();	

	while (1)
	{
		wdt_reset();

		// Handle any packets that may have come in
		if (mrbusPktQueueDepth(&mrbusRxQueue))
			PktHandler();

		if (eventFlags & EVENT_DO_BD_READ)
		{
			changed = readDetectors();
			
			eventFlags &= ~(EVENT_DO_BD_READ);
			ADCSRA |= _BV(ADSC);			
		}

		if (decisecs >= update_decisecs)		
		{
			ATOMIC_BLOCK(ATOMIC_FORCEON)
			{
				decisecs -= update_decisecs;
			}
			changed = 1;
		}

		// If we need to send a packet and the TX queue isn't full...
		if (changed && !(mrbusPktQueueFull(&mrbusTxQueue)))
		{
			uint8_t txBuffer[10];

			txBuffer[MRBUS_PKT_SRC] = mrbus_dev_addr;
			txBuffer[MRBUS_PKT_DEST] = 0xFF;
			txBuffer[MRBUS_PKT_LEN] = 8;
			txBuffer[5] = 'S';
			txBuffer[6] = internalBDStatus;
			txBuffer[7] = externalBDStatus;

			mrbusPktQueuePush(&mrbusTxQueue, txBuffer, txBuffer[MRBUS_PKT_LEN]);
			changed = 0;
		}

		if (mrbusPktQueueDepth(&mrbusTxQueue) && 0 == busTimeout)
		{
			uint8_t fail = mrbusTransmit();
			// If we failed to transmit, just take some number of 10mS increments to wait until trying again, minimum of 40mS
			if (fail)
				busTimeout = 4 + (mrbus_dev_addr & 0x0F);
		}
	}
}

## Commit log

2012-03-19 Added schematic for the BD42
    [mrb-bd42.sch]
2012-03-19 Initial version of the mrb-bd42 source code.
    NOTE: This doesn't correspond to the schematics. This is targetted at a attiny2313
    [mrb-bd42.c]
2012-03-21 Updates to the schematic
    [mrb-bd42.sch]
2012-03-21 Initial PCB
2012-03-21 Latest update to the schematic
    [mrb-bd42.sch]
2012-03-21 Last round of updates for tonight
    [mrb-bd42.sch]
2012-03-21 Forgot to turn off the footprints on the jacks
    [mrb-bd42.sch]
2012-03-21 Okay, one more update
    [mrb-bd42.sch]
2012-03-21 Updates as suggested by Michael
    [mrb-bd42.sch]
2012-03-23 Corrected schematic
    [mrb-bd42.sch]
2012-03-23 First finished version of the MRB-BD4
    [mrb-bd42.sch]
2012-03-23 Forgot to set the board size back after placing all components
2012-03-24 Forgot to add PKT and PWR to the main LEDs
2012-03-24 Fixed pot hole sizes
2012-03-26 Changes to get TO-220 7805 rather than SOT-89 - needed for current drawn by BD4X boards.
    [mrb-bd42.sch]
2012-04-08 Updates to get rid of a timer-based pb change
2012-04-22 Fix for reading the internal sensors
    [mrb-bd42.c]
2013-03-28 New PG files compatible with panelizer script.
    [mrb-bd42.bottom.gbr, mrb-bd42.bottommask.gbr, mrb-bd42.bottompaste.gbr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]
2013-04-09 Increased TQFP soldermask clearance.
2013-04-09 PG files for panel
    [mrb-bd42.bottom.gbr, mrb-bd42.bottommask.gbr, mrb-bd42.bottompaste.gbr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]
2013-05-17 Fixed one non-atomic volatile access Added additional WDT resets, just in case
    [mrb-bd42.c]
2014-12-08 New schematic with redesigned current transformer detection circuits
    [mrb-bd42.sch]
2014-12-08 Fixes for bd42 source - previous checkin didn't work correctly
    [mrb-bd42.c]
2015-01-03 Misc fixes and new v2.0 PCB layout
    [mrb-bd42.sch]
2015-03-01 Update to v2.1 - change diode symbol to match footprint being used (was reversed in v2.0)
    [mrb-bd42.sch]
2015-03-02 Flip around the SOD123 outline
    [mrb-bd42.sch]
2015-04-09 Initial draft of MRB-BD42 v3.0
    [mrb-bd42.sch]
2015-04-09 Fix up some footprint issues
    [mrb-bd42.sch]
2015-04-18 Remove conflict between input diode and transformer diodes
    [mrb-bd42.sch]
2015-04-19 New v3.0 BD42
    [mrb-bd42.sch]
2015-04-19 Intermediate step in joining BD42 and BD4X designs
    [mrb-bd42.sch]
2015-04-19 Modifications for dual use as mrb-bd42 and mrb-bd4x
    [mrb-bd42.sch]
2015-04-20 Fixes suggested in design review
    [mrb-bd42.sch]
2015-05-10 Modify for v3.1 - fix issue where a ballast resistor is needed on the 1.2V bias rail in order to deal with current sourced into the node by the op amp feedback circuits
    [mrb-bd42.sch]
2015-05-11 Add terminal blocks for use as a dedicated block detector
    [mrb-bd42.sch]
2015-05-18 tapeout of v3.1 pcb to go to manufacturing
    [mrb-bd42.bottom.gbr, mrb-bd42.bottommask.gbr, mrb-bd42.bottompaste.gbr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]
2015-05-18 Add legacy v3.0 pg - this has been superceded by v3.1, but putting it here for historical reasons
    [mrb-bd42.bottom.gbr, mrb-bd42.bottommask.gbr, mrb-bd42.bottompaste.gbr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]
2015-08-16 Initial cut of bd4x expander firmware
2016-06-05 Experimental fix to try to deal with bus contention issues
    [mrb-bd42.c]
2016-12-08 Cleanup and make BD4X run on internal RC oscillator rather than crystal
    [mrb-bd4x.c]
2016-12-08 Update ADC prescaler to be 156kHz rather than 312kHz Fix issue where update interval isn't reloaded on initial reset Update hardware rev to 3.1
    [mrb-bd42.c]
